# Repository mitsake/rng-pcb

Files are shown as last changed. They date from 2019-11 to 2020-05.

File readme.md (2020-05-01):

# CircuitPython Random Number Generator

This is my contribution to the Boldport Club's community run Board Swap Project, a hardware random number generator that uses avalanche noise to make patterns and roll dice. Apart from being part of the community project, my other motivations were interest in randomness and the processes that can be used to generate it, along with the idea of using PCBs to build an enclosure.

**Please note that I made this for fun - if you need random numbers for anything important, this isn't the project you're looking for.**

## Operation

A ST662 charge pump produces the 12 V required to reverse-bias Q1, which produces the actual randomness. When electrons travel through this junction, Q2 allows current to flow to ground. This signal is amplified by Q3, run through a voltage divider, and fed into the ADC of an ATSAMD21E18 microcontroller, which has been flashed with the [Adafruit Trinket M0][trinket] bootloader to allow programming with CircuitPython.

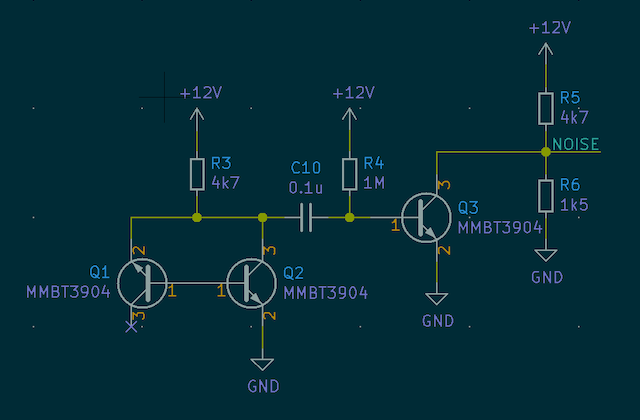
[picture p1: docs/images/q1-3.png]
Electronic schematic showing three transistors connected in a way that produces random noise


[trinket]: https://www.adafruit.com/product/3500

The display is an inexpensive 128 × 32 SSD1306-based OLED, and the in-built capacitive touch that's on the Trinket M0 hardware is routed to the top left (pin A3) and right (A4) corners of the top PCB to allow for input. If you don't have KiCad, you can use the [PDF schematic][schematic] - it's all pretty simple.

[schematic]: docs/schematic.pdf

## Making your own

You can use the KiCad files in the 'hardware' directory to generate gerbers and get them made at your favourite PCB fab. I had my prototypes made at [OSH Park][oshpark] (who accept the `.kicad_pcb` file directly), and once I'd finished the final design, got a 'protopack' made at [Dirty PCBs][dirtypcbs]. The gerbers are available in a [zip file][zip] which should be accepted by most fabs, and assembly instructions can be found [here][assembly]. Make sure the PCB thickness is 1.6 mm - Dirty PCBs default to 1.2 mm, which will cause clearance issues.

[oshpark]: https://www.oshpark.com/
[dirtypcbs]: https://dirtypcbs.com/store/pcbs/
[assembly]: docs/assembly.md
[zip]: hardware/gerbers/rng-pcb-dirtypcbs.zip

## Credits

This project was only possible thanks to the electrical designs, libraries, and articles written by others. Many thanks to the people below whose work was used to build this project, and to the Boldport Club Discord for the inspiration to build something and the help and support they're always happy to provide.

- Adafruit's [Trinket M0 schematic][m0schem], which I shamelessly copied for the microcontroller and its supporting components. I've also used Adafruit's bootloader (and consequently their USB VID and PID), so this project is strictly a DIY build. Please don't distribute finished versions of this project with the Adafruit bootloader installed.
- Aaron Logue's [Hardware Random Number Generator][aaronl] started me on the path towards making the project, and gave the basic circuit.
- Giorgio Vazzana's [amazing writeup][giorgiov] of his experiments with this design, including precise measurements of transistor breakdown voltages, analogue and digital output circuits, and rigorous testing of the output.
- Walter Anderson's [Google Sites][waltera] page has a lot of really interesting information on entropy, both from this design and others.
- Rob Seward's [Arduino Uno design][robs] feeds the output from the noise circuit into an ADC and uses software to produce the actual random bits, an approach I mostly copied.
- The pattern on the top PCB (`triangle_pattern.kicad_mod`) is made with Quinn Rohlf's [Trianglify][trianglify] library.
- The `mouse-bite-2mm-slot.kicad_mod` footprint comes from [this repository][madworm] by madworm.

[m0schem]: https://learn.adafruit.com/assets/45723
[aaronl]: http://www.cryogenius.com/hardware/rng/
[giorgiov]: http://holdenc.altervista.org/avalanche/index.html
[waltera]: https://sites.google.com/site/astudyofentropy/project-definition/avalanche-noise
[robs]: http://robseward.com/misc/RNG2/
[trianglify]: https://github.com/qrohlf/trianglify
[madworm]: https://github.com/madworm/Panelization.pretty

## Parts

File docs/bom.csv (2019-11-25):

Reference | Quantity | Value | Footprint | Digikey | Mouser
C1, C7 | 2 | 10 μF, 16 V | 0603 | 1276-6769-1-ND | 81-GRM188C81C106MA3D
C2, C3 | 2 | 0.22 μF, 16 V | 0603 | 1276-1112-1-ND | 81-GCJ188R71C224KA1D
C4, C5, C8, C10 | 4 | 0.1 μF, 16 V | 0603 | 1276-1005-1-ND | 81-GCJ188R71C105KA1D
C6, C9 | 2 | 1 μF, 16 V | 0603 | 1276-6524-1-ND | 81-GCM188R71C105KA4J
J1 | 1 | USB-micro jack | Molex 47642-0001 | WM1398CT-ND | 538-47642-0001
J2 | 1 | 128 × 32 OLED | 1×4 pin header
Q1, Q2, Q3 | 3 | MMBT3904T | SOT416 (aka SOT523) | MMBT3904T-FDICT-ND | 621-MMBT3904T-F
R1, R2, R3, R5 | 4 | 4.7 kΩ | 0603 | 311-4.70KHRCT-ND | 603-RC0603FR-074K7L
R4 | 1 | 1 MΩ | 0603 | 311-1.00MHRCT-ND | 603-RC0603FR-071ML
R6 | 1 | 1.5 kΩ | 0603 | 311-1.50KHRCT-ND | 603-RC0603FR-071K5L
SW1 | 1 | Push switch | Wurth 434331013822 | 732-10144-1-ND | 710-434331013822
U1 | 1 | AP2112K-3.3 | SOT 23-5 | AP2112K-3.3TRG1DICT-ND | 621-AP2112K-3.3TRG1
U2 | 1 | ST662A | SOIC-8 | 497-6541-1-ND | 511-ST662ABD-TR
U3 | 1 | ATSAMD21E18A | TQFP-32 | ATSAMD21E18A-AUTCT-ND | 556-ATSAMD21E18A-AUT

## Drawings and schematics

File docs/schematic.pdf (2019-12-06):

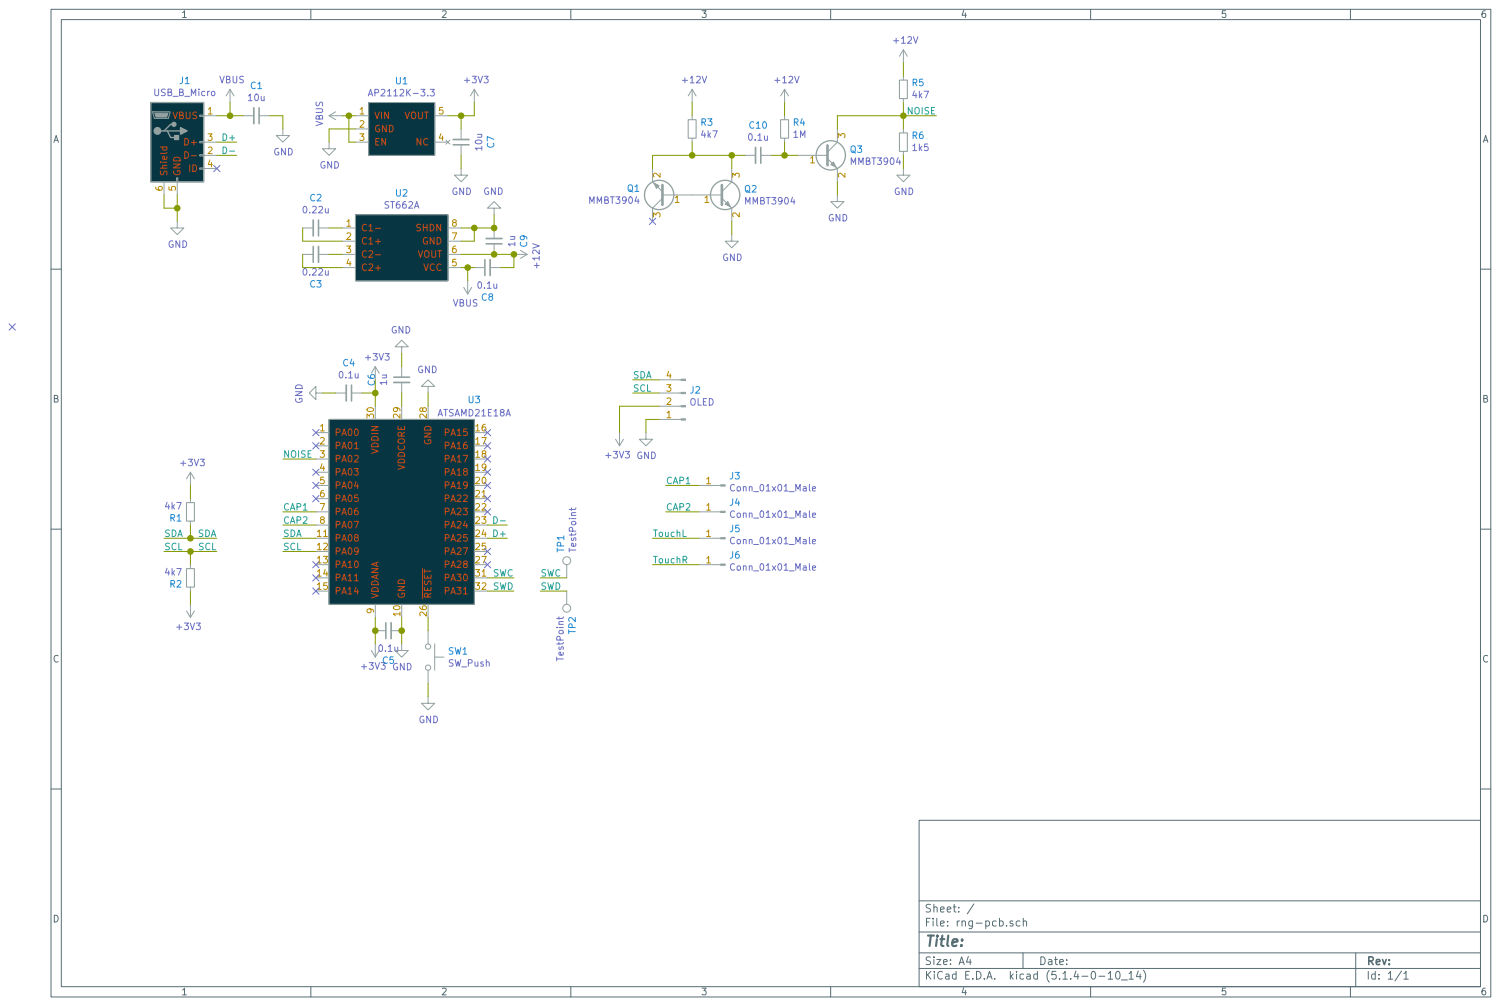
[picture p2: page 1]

J6Conn_01x01_Male
File: rng-pcb.sch Sheet: / 1

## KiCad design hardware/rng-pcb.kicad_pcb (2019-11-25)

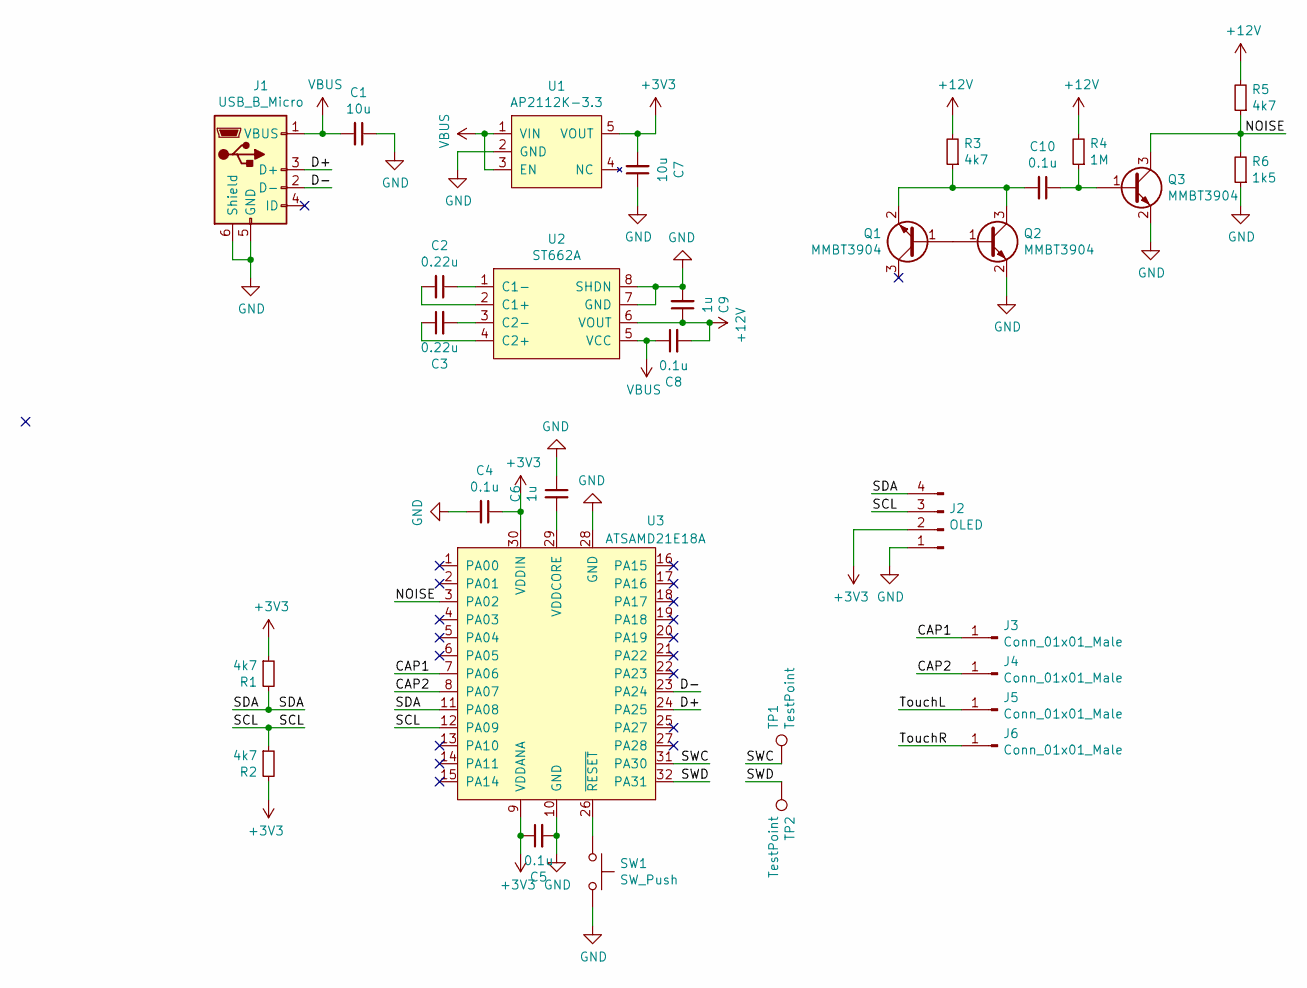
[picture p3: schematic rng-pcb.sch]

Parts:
C1, C7: 10u; C_0603
C2, C3: 0.22u; C_0603
C4, C5, C8, C10: 0.1u; C_0603
C6, C9: 1u; C_0603
J1: USB_B_Micro; Molex-476420001
J2: OLED; PinHeader_1x04_P2.54mm_Vertical
J3, J4, J5, J6: Conn_01x01_Male; TH_Pad
Q1, Q2, Q3: MMBT3904; SOT523
R1, R2, R3, R5: 4k7; R_0603
R4: 1M; R_0603
R6: 1k5; R_0603
SW1: SW_Push; Wurth-434331013822
TP1, TP2: TestPoint; Test_Point_Pad_d1.0mm
U1: AP2112K-3.3; TSOT-23-5
U2: ST662A; SOIC-8_3.9x4.9mm_Pitch1.27mm
U3: ATSAMD21E18A; TQFP-32_7x7mm_Pitch0.8mm

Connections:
+3V3: C4.1, C5.1, C7.2, J2.2, R1.1, R2.2, U1.5 (VOUT), U3.9 (VDDANA), U3.30 (VDDIN)
+12V: C8.2, C9.1, R3.2, R4.2, R5.2, U2.6 (VOUT)
/CAP1: J3.1, U3.7 (PA06)
/CAP2: J4.1, U3.8 (PA07)
/D+: J1.3 (D+), U3.24 (PA25)
/D-: J1.2 (D-), U3.23 (PA24)
/NOISE: Q3.3 (C), R5.1, R6.2, U3.3 (PA02)
/SCL: J2.3, R2.1, U3.12 (PA09)
/SDA: J2.4, R1.2, U3.11 (PA08)
/SWC: TP1.1, U3.31 (PA30)
/SWD: TP2.1, U3.32 (PA31)
/TouchL: J5.1
/TouchR: J6.1
GND: C1.1, C4.2, C5.2, C6.1, C7.1, C9.2, J1.5 (GND), J1.6 (Shield), J2.1, Q2.2 (E), Q3.2 (E), R6.1, SW1.2, U1.2 (GND), U2.7 (GND), U2.8 (SHDN), U3.10 (GND), U3.28 (GND)
unnamed: C2.1, U2.1 (C1-)
unnamed: C2.2, U2.2 (C1+)
unnamed: C3.1, U2.4 (C2+)
unnamed: C3.2, U2.3 (C2-)
unnamed: C6.2, U3.29 (VDDCORE)
unnamed: C10.1, Q3.1 (B), R4.1
unnamed: C10.2, Q1.2 (E), Q2.3 (C), R3.1
unnamed: Q1.1 (B), Q2.1 (B)
unnamed: SW1.1, U3.26 (~RESET)
VBUS: C1.2, C8.1, J1.1 (VBUS), U1.1 (VIN), U1.3 (EN), U2.5 (VCC)

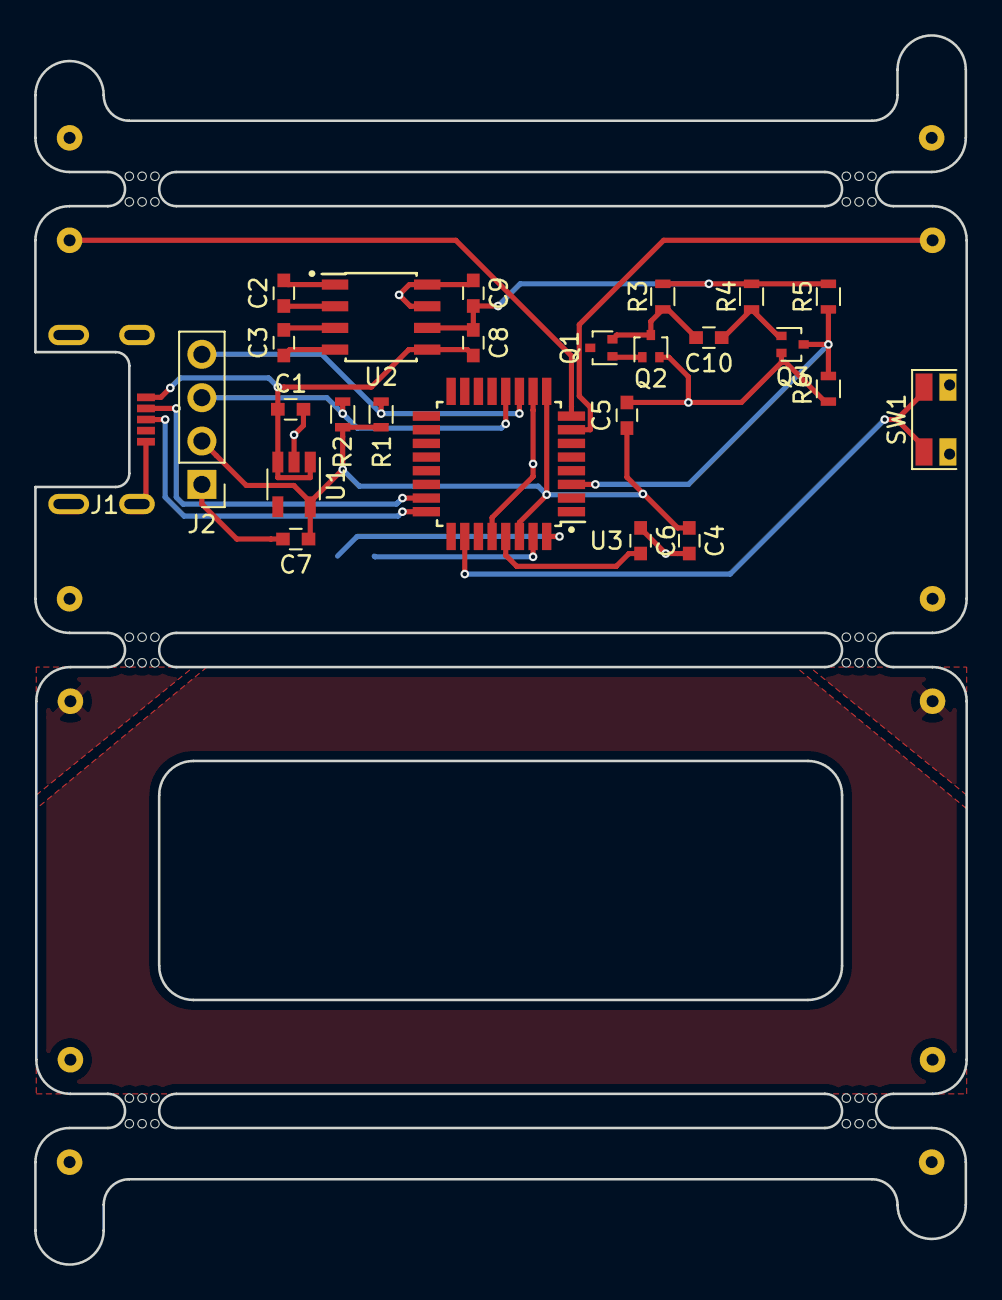
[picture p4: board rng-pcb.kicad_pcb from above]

Board: 2 copper layers, 54.6 x 72.0 mm, 37 parts (0 on the bottom side), 22 nets.

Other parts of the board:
mouse-bite-2mm-slot, mouse-bite-2mm-slot#2, mouse-bite-2mm-slot#3, mouse-bite-2mm-slot#4, mouse-bite-2mm-slot#5, mouse-bite-2mm-slot#6: VAL**; mouse-bite-2mm-slot

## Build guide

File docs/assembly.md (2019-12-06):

# Assembly instructions

## Materials

### Components

Apart from the parts in the [bill of materials][bom], you'll need to source a screen. The best places to find these are the usual suspects - AliExpress, eBay, or wherever else you find your cheap electronics. I used [this one][screen], though I should have bought one with a black PCB to better fit the final boards! One thing to watch out for are the dimensions; I've noticed that some sellers (e.g. [this one][wrongscreen]) have pictures that show a longer version.

[bom]: bom.csv
[screen]: https://www.aliexpress.com/item/32672229793.html
[wrongscreen]: https://www.aliexpress.com/item/32788923016.html

### Tools etc.

- Soldering iron or hot air station
- Solder wire (and paste if you're using hot air)
- Flux
- Desoldering braid
- Flush cutters
- About 50-80 mm of ~ 0.5 mm diameter wire - leads from through-hole resistors work well
- A way to flash the microcontroller - I used a [J-Link EDU Mini][jlink].

[jlink]: https://www.segger.com/products/debug-probes/j-link/models/j-link-edu-mini/

## Separate the boards

There are four boards in the design: the bottom board, which will have all the components soldered to it; two 'spacers', which do exactly what their name suggests; and the top board, which acts as a screen bezel and breaks out the two capacitive touch pads. Use a set of side cutters to cut the mouse bites connecting the boards, and clean them up with a file or some sandpaper.

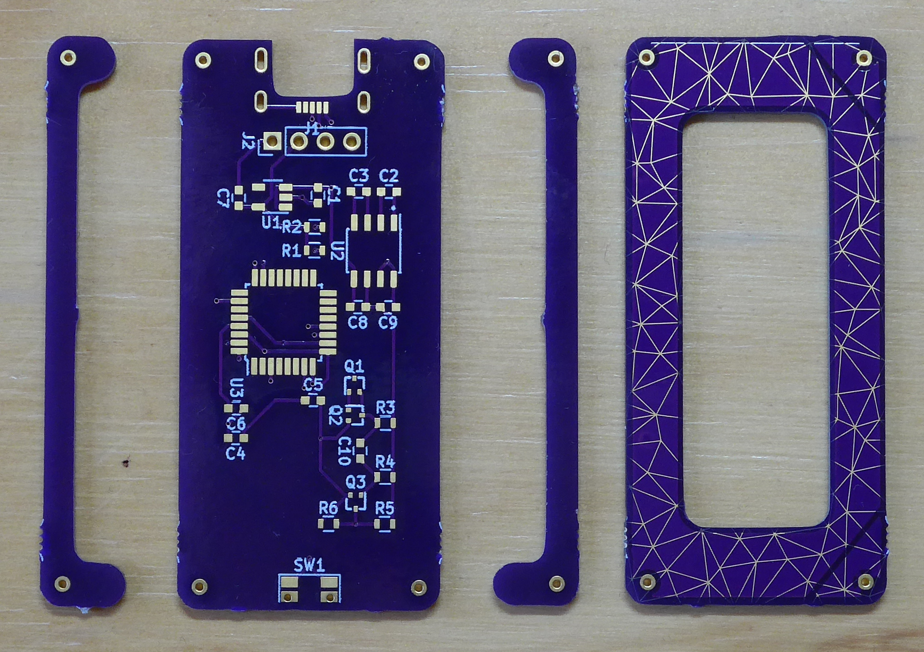
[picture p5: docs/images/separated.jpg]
Four small printed circuit boards


## Populate the bottom board

With the four boards separated, the next job is to solder all the components (except the OLED screen) to the bottom board. My preference is for the following order:

1. Transistors (Q1-3)
2. Resistors and capacitors
3. ICs (U1-3)
4. Reset switch (SW1) and USB jack (J1)

There are lots of guides out there for SMD soldering, but some things to look out for:

- The ST662A (U2) chip package has a bevel on the side of pin 1. Note also that the 12 V output and ground pins are next to each other and there's no overcurrent protection - if you short them while the board has power, the magic smoke will come out.
- The collector pin (pin 3) of Q1 is unconnected, so the pad will lift very easily (depending on who made your boards). Don't panic if it happens, only pins 1 and 2 need to be connected!
- If you're hand soldering, remember that more flux is the answer to most problems.

Hopefully once you're done, you'll have something that looks like this:

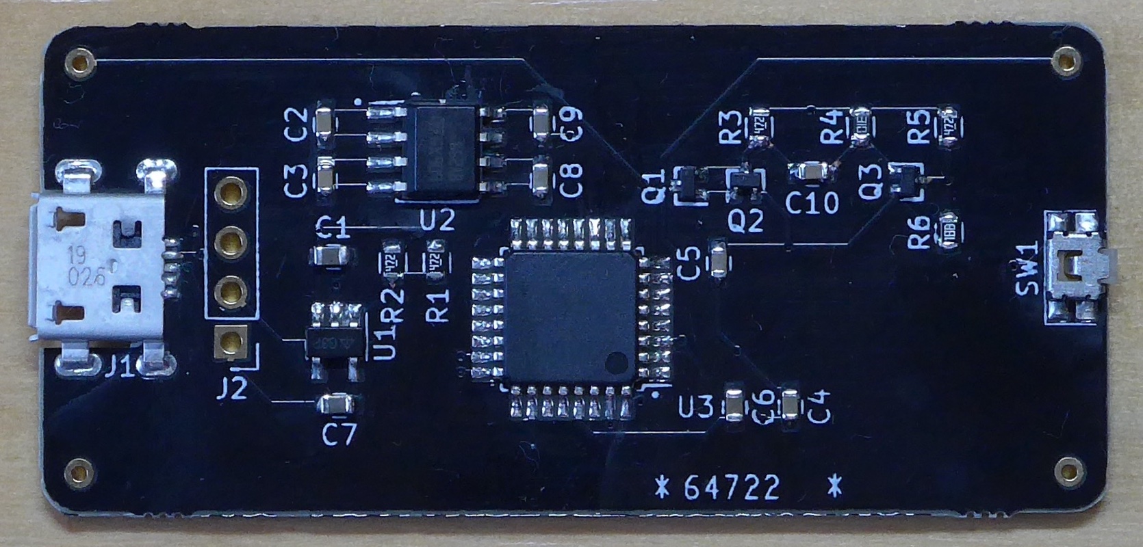
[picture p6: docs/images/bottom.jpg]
Printed circuit board with surface-mount components soldered to it


## Flash the UF2 bootloader

As this project is based on Adafruit's [Trinket M0][trinket], we need to install the [UF2 bootloader][bootloader] for that board. The SWC and SWD pins are routed to the bottom of the board, and tacking some wires to these should be sufficient. If you don't have a J-Link on hand, there are quite a few ways to flash via SWD, such as OpenOCD on a [Raspberry Pi][piocd] or [FTDI FT232H][FT232H] breakout, or [converting][bluetobmp] a cheap STM32 'Blue Pill' to a [Black Magic Probe][bmp].

[trinket]: https://www.adafruit.com/product/3500
[bootloader]: https://github.com/adafruit/uf2-samdx1
[piocd]: https://learn.adafruit.com/programming-microcontrollers-using-openocd-on-raspberry-pi
[FT232H]: https://github.com/unprovable/FTDI-Oh-My/blob/master/FT232H-JTAG-SWD.txt
[bluetobmp]: https://medium.com/@paramaggarwal/converting-an-stm32f103-board-to-a-black-magic-probe-c013cf2cc38c
[bmp]: https://github.com/blacksphere/blackmagic

## Install CircuitPython and required libraries

If flashing was successful, resetting the boards should result in a USB mass-storage device called TRINKETBOOT appearing on your computer. It's then a simple matter of downloading the [latest release][CircuytPyDL] of CircuitPython for the Trinket, copying that to the mass storage device, and waiting until a new device called CIRCUITPY appears. You'll also need a copy of the [libraries][] that match the version of CircuitPython installed, and copy `adafruit_bus_device` (the whole directory), `adafruit_framebuf.mpy` and `adafruit_ssd1306.mpy` to the `lib` folder on the drive. In addition, `font5x8.bin` (found in the examples folder) should be copied to the root of the drive.

[CircuitPyDL]: https://circuitpython.org/board/trinket_m0/
[libraries]: https://circuitpython.org/libraries

## Test the screen

Before you finish assembly, test the screen! It'll be really hard to get to any of the components once everything is put together. Put the following into `code.py` (or use the REPL).

``` python
import board
import busio
import adafruit_ssd1306

i2c = busio.I2C(board.SCL, board.SDA)
oled = adafruit_ssd1306.SSD1306_I2C(128, 32, i2c)

oled.text('Hello world!', 0, 0, 1)
oled.show()
```

Insert the screen into the connector, hold it on an angle to ensure there's an electrical connection, and run the code. Hopefully the screen will greet you.

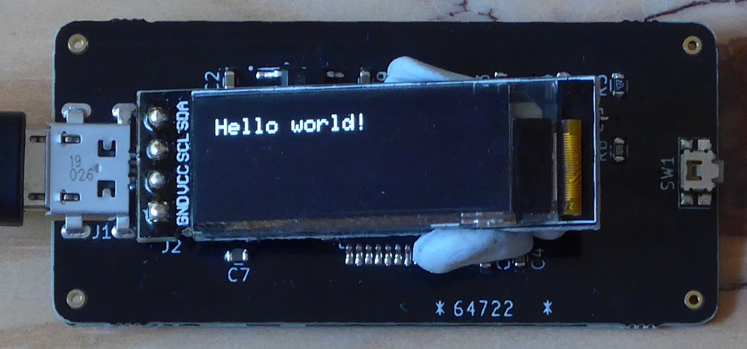
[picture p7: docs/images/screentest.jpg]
Circuit board with screen displaying 'Hello world!'


## Build the PCB stack

Now that everything's working, the boards can be stacked to make the enclosure. Cut the wire into four segments, insert them into the bottom PCB, and solder them from the bottom side:

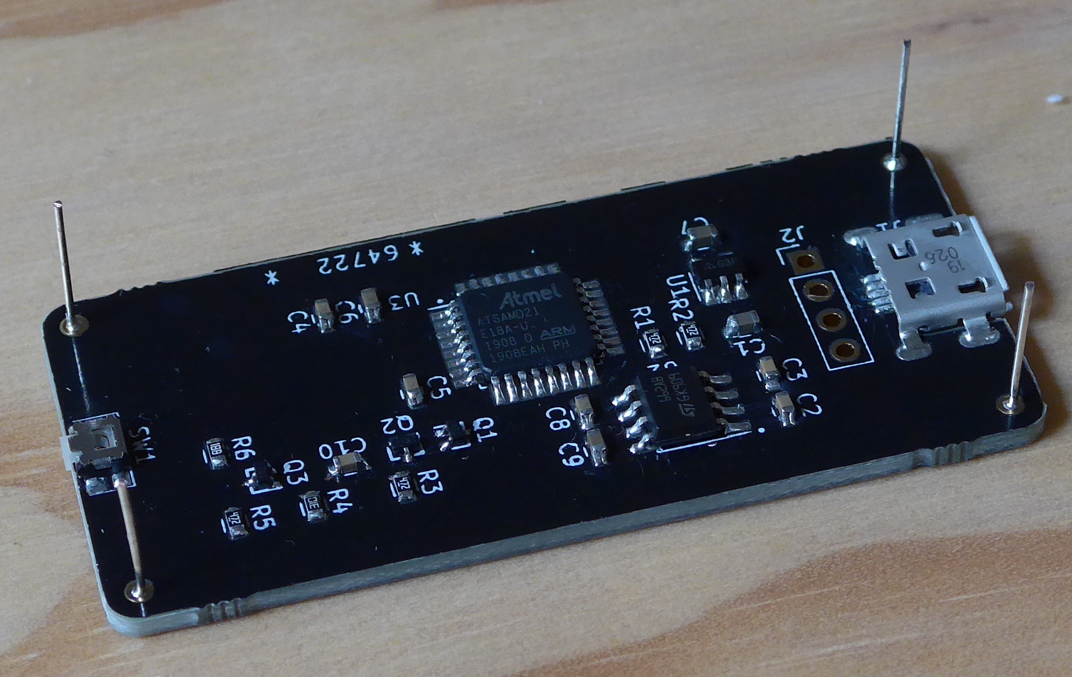
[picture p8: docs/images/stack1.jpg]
Circuit board with a wire sticking up from each corner


Thread the spacers onto the wires - make sure they're the right way around! The shorter arm should be located on the same side as the USB connector. You can solder these in place, but use as little as possible so that the top board can sit flush.

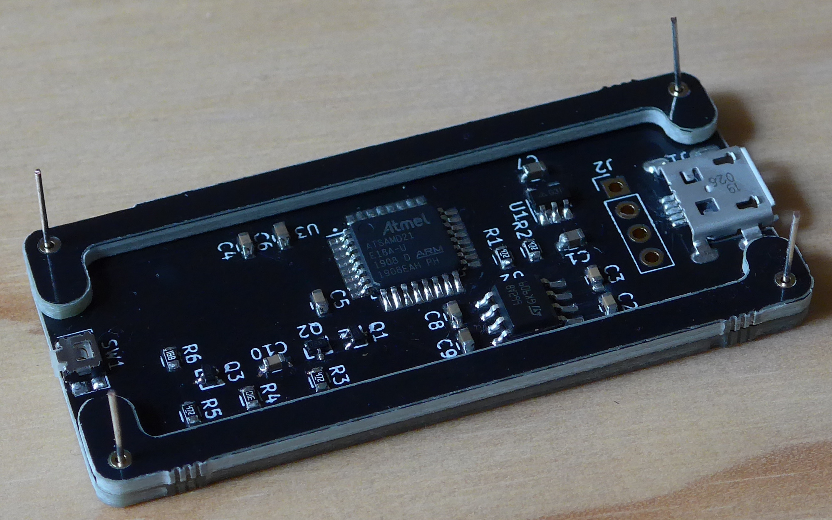
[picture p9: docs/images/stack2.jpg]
Circuit board with two small boards sitting on top. The boards are held in place with wires


Finally, put the top board in place, paying attention to direction. The top of the board has two diagonal lines in the top left and right of the board, which act as the capacitive touch points. Solder in place.

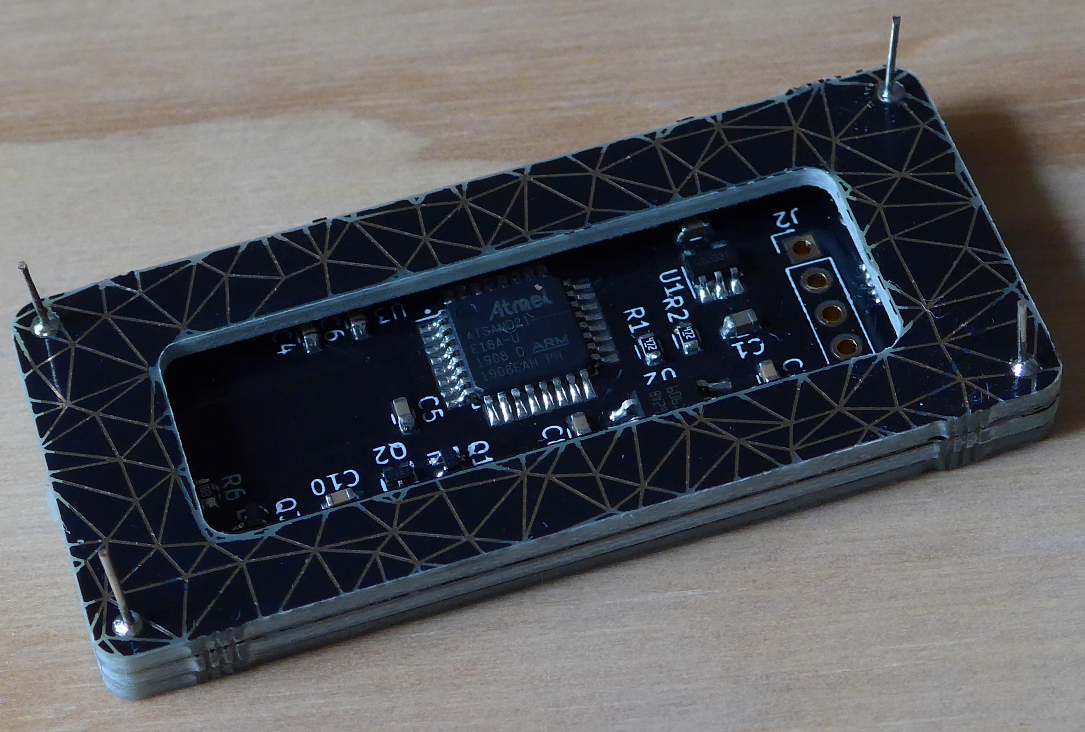
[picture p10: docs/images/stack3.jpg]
A stack of three circuit boards. All boards are held in place with wires that stick out of each corner


## Attach the screen

The screen fits best if you remove the plastic from the four-pin header with pliers.

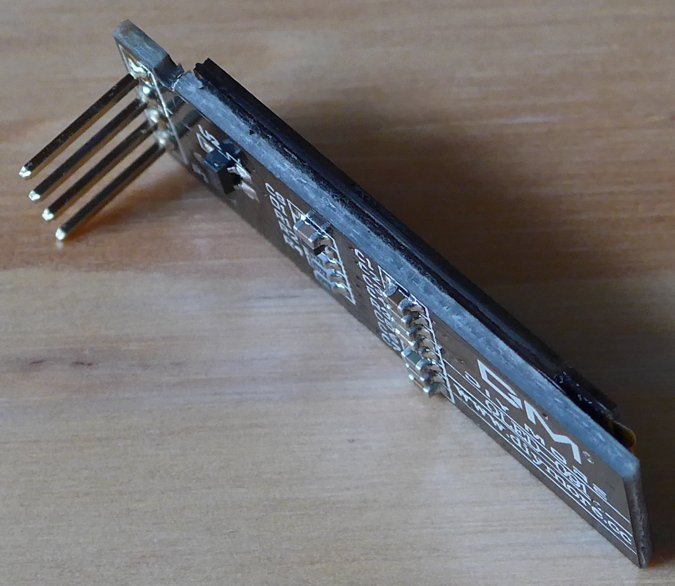
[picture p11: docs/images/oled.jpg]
A small OLED screen. The four-pin header has had the black plastic spacer removed


Doing this lets the screen sit on top of the microcontroller and mostly flush with the top PCB. Once you've got the screen in position, flip the stack of boards over and solder the screen in place.

## All done!

In the spirit of the Club, finish all the through-hole joints with beautiful [solder domes][domes], and your random number generator is ready to receive code!

[domes]: https://boldport.com/blog/2014/03/making-beautiful-solder-points.html

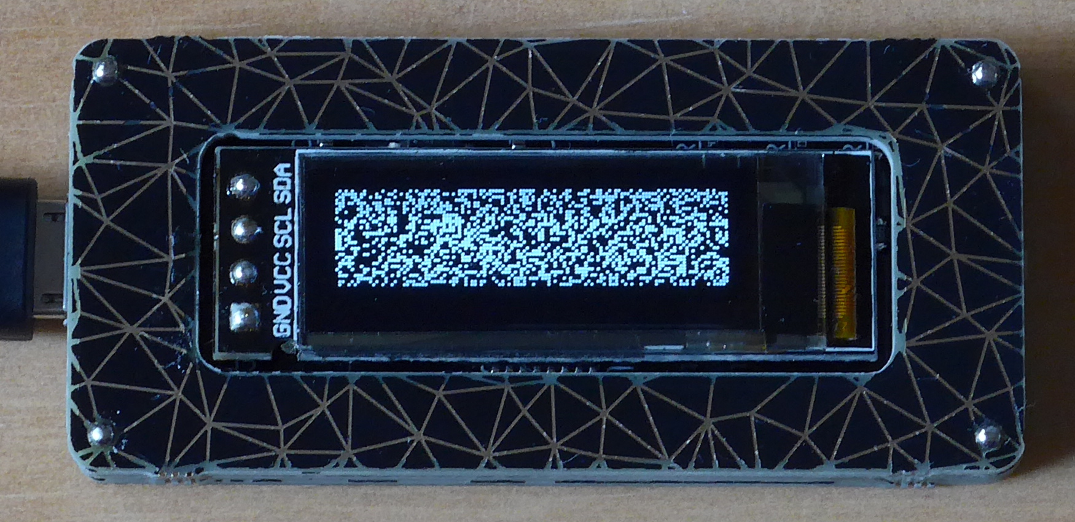
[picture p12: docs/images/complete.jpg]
A small device with a pattern of triangles around the outside. In the centre of the board is a small screen displaying static.


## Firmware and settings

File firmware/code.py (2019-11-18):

import board
import busio
import sys
import touchio
import adafruit_ssd1306
from analogio import AnalogIn

i2c = busio.I2C(board.SCL, board.SDA)
oled = adafruit_ssd1306.SSD1306_I2C(128, 32, i2c)
noise_in = AnalogIn(board.A0)
touch_r = touchio.TouchIn(board.A4)
touch_l = touchio.TouchIn(board.A3)

oled.fill(0)
oled.text("Right: pattern", 0, 0, 1)
oled.text("Left: noise values", 0, 10, 1)
oled.show()

while True:
    if touch_r.value:
        oled.fill(0)
        oled.show()
        for row in range(128):
            for col in range(32):
                last_digit = noise_in.value % 10
                if last_digit in [2, 4]:
                    oled.pixel(row, col, 0)
                    # print(0)
                elif last_digit in [6, 8]:
                    oled.pixel(row, col, 1)
                    # print(1)
        oled.show()

    if touch_l.value:
        oled.fill(0)
        oled.text("RNG -> serial", 0, 0, 1)
        oled.show()
        while True:
            out_byte = 0
            count = 0
            while count < 8:
                last_digit = noise_in.value % 10
                if last_digit in [2, 4]:
                    count = count + 1
                    #print(0)
                elif last_digit in [6, 8]:
                    mask = 1 << count
                    out_byte = out_byte ^ mask
                    count = count + 1
                    #print(1)
            sys.stdout.write(bytes([out_byte]))
                    

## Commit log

2019-11-25 Finished assembly and removed old (low-quality) picture
2019-11-25 Created separate BOM
2019-11-25 Added bom.csv
    [bom.csv]
2019-11-25 BOM updates, footprints changed
    [bom.csv, rng-pcb.kicad_pcb]
2019-12-06 Final images and PDF schematic added
